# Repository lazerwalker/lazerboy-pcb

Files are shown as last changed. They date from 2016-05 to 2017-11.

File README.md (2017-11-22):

# Game Boy Button PCB

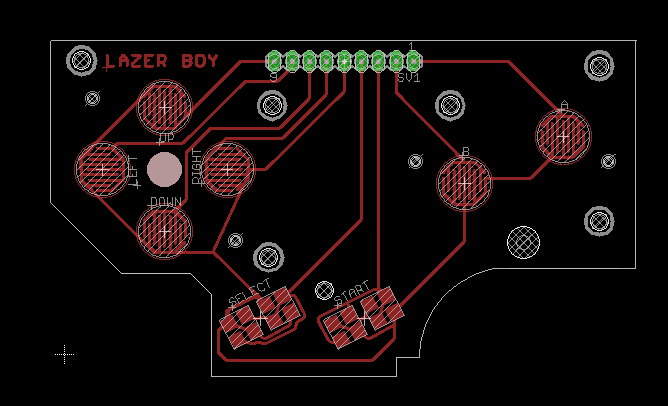
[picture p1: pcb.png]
PCB Picture of the PCB in EagleCAD


This is a PCB that fits into a Nintendo DMG-1 (1989 Game Boy) shell. It's designed to take in button input, with traces that fit the original button placement, and route them to a convenient 9-pin output (4-way d-pad, A/B/Start/Select buttons, common ground). In my case, I connect them directly to the GPIO of a Raspberry Pi Zero.

It's based on Rolf's [DMG-Rolf](http://gbdev.gg8.se/files/schematics/DMG-Rolf/) project, but far simplified since this board contains only button contacts and no actual logic.

## License

This work is licensed under the Creative Commons Attribution-NonCommercial-ShareAlike 2.5 Canada License. To view a copy of this license, visit http://creativecommons.org/licenses/by-nc-sa/2.5/ca/ or send a letter to Creative Commons, 444 Castro Street, Suite 900, Mountain View, California, 94041, USA.

If you have any questions, comments, or concerns, please email the original creator of these files at chrisweird@gmail.com, or the creator of this derivative project at gb@lazerwalker.com

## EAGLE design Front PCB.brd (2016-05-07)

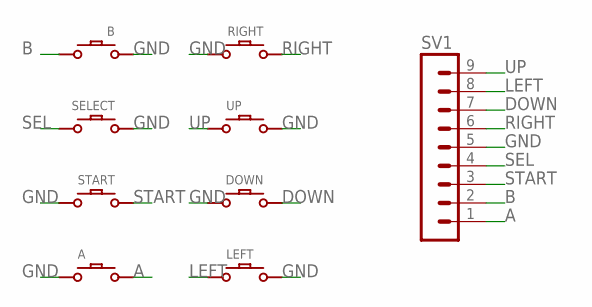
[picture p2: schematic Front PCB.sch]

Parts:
A: DMG-BTN
B: DMG-BTN
DOWN: DMG-BTN
LEFT: DMG-BTN
RIGHT: DMG-BTN
SELECT: DMG-BTN; DMG-SEL
START: DMG-BTN; DMG-ST
SV1: MA09-1
UP: DMG-BTN

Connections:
A: A.P$2, SV1.1
B: B.P$2, SV1.2
DOWN: DOWN.P$1, SV1.7
GND: A.P$1, B.P$1, DOWN.P$2, LEFT.P$2, RIGHT.P$2, SELECT.P$1, START.P$2, SV1.5, UP.P$2
LEFT: LEFT.P$1, SV1.8
RIGHT: RIGHT.P$1, SV1.6
SEL: SELECT.P$2, SV1.4
START: START.P$1, SV1.3
UP: SV1.9, UP.P$1

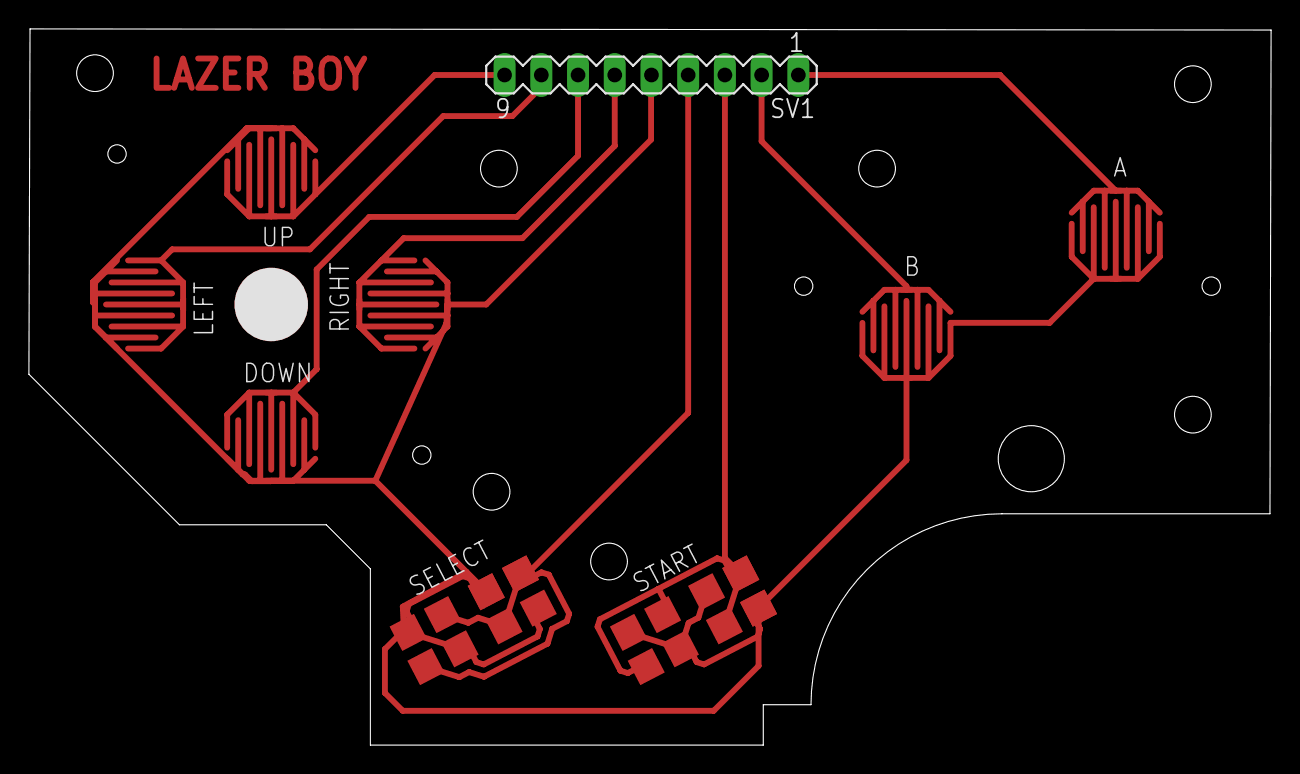
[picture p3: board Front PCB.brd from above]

Board: 2 copper layers, 85.9 x 49.5 mm, 9 parts (0 on the bottom side), 9 nets.

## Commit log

2016-05-06 Remove unused boards
    [DMG Headphone.brd, DMG Headphone.sch, DMG Motherboard.brd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]
2016-05-07 Redesign board to use through-hole pins
    [Front PCB.brd, Front PCB.sch]
2016-05-07 Crop slightly on top
    To avoid collisions with the screen I'm using. Longer forehead was
    necessary when there were horizontal headers sticking out.
    [Front PCB.brd]
2016-05-07 Try making small holes smaller
    [Front PCB.brd]
